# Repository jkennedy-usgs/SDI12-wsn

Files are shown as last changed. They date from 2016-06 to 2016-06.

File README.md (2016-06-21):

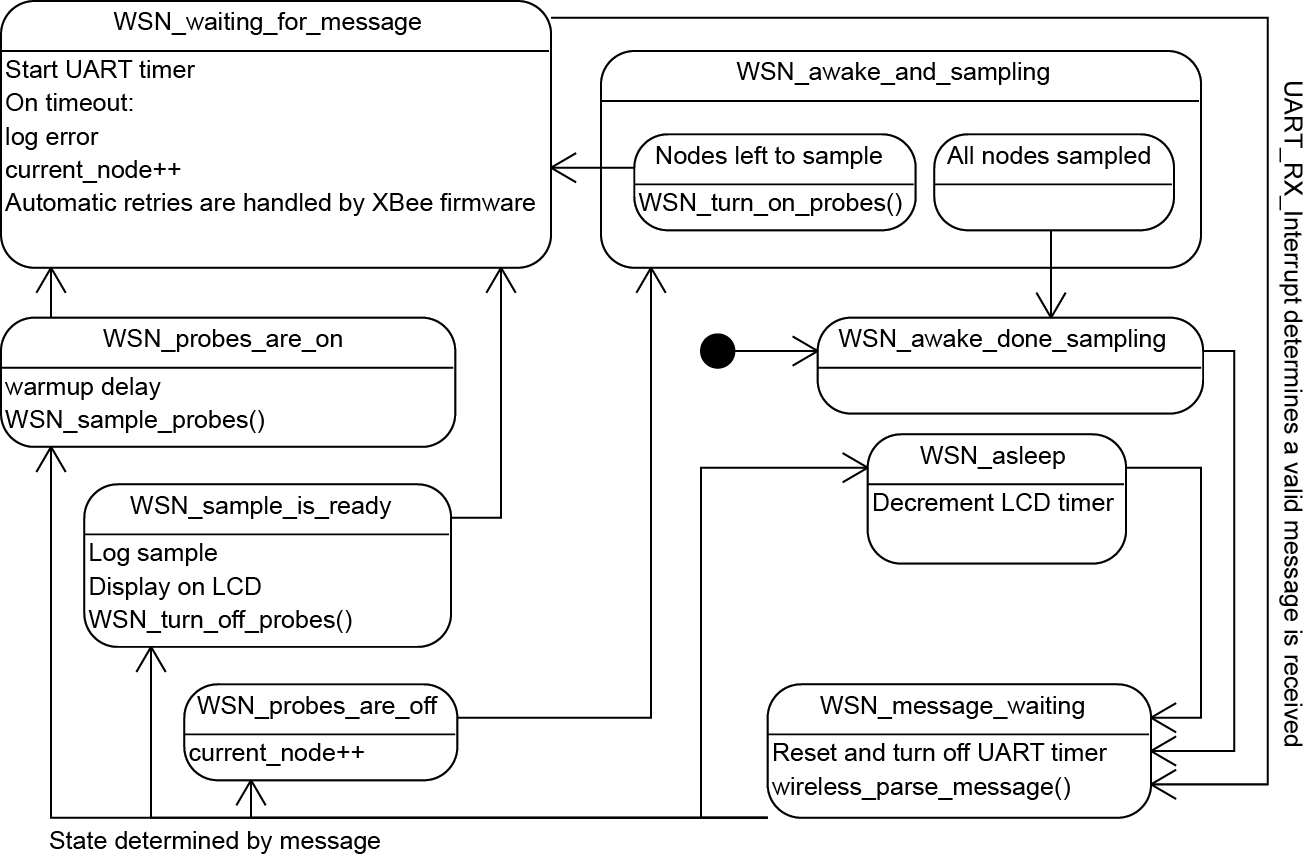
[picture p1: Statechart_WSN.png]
State chart

# SDI12-wsn
C interface for SDI-12 communication on Atmel AVR and XBee nodes

This project is intended to allow wireless sensor networks - in particular, XBee devices - to be deployed at dataloggers with a host SDI-12 port. The data logger issues normal SDI-12 commands to a "bridge" device, which coordinates communication among the devices in the wireless sensor network. The benefit is that a local wireless network, using low-power radios, can relay data through an existing satellite telemetry network that uses data loggers with (usually ubiquitous) SDI-12 ports.

Additional detail is provided in the conference abstract and poster here:
https://www.researchgate.net/publication/266385447_Expanding_the_Usefulness_of_Existing_Data-Collection_Infrastructure_with_Wireless_Sensor_Networks
and in the draft manuscript provided in the Word document. 

The project includes c code to run on an AVR microcontroller and schematics and board layouts for producing PCB's for the bridge and node unit. The nodes are intended for use with voltage-output soil moisture probes but could be modified for other sensors. NOTE: the project is not designed to implement SDI-12 sensors in a wireless sensor network. 

The project was originally developed in 2010, and bench tested successfully. The hardware has not been field tested. 

The software and related documentation on these web pages were developed by the U.S. Geological Survey (USGS) for use by the USGS in fulfilling its mission. The software can be used, copied, modified, and distributed without any fee or cost. Use of appropriate credit is requested. The USGS provides no warranty, expressed or implied, as to the correctness of the furnished software or the suitability for any purpose. The software has been tested, but as with any complex software, there could be undetected errors.

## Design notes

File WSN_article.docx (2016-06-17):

This draft manuscripts provides an overview of the SDI12-wsn project hosted at https://github.com/jkennedy-usgs/SDI12-wsn. THE MANUSCRIPT HAS NOT BEEN REVIEWED BY USGS AND IS NOT AN OFFICIAL PUBLICATION. It is provided for informational purpose only.

Adaptation of the SDI-12 protocol for easy deployment earth science wireless sensor networks

Jeffrey Kennedy, U.S. Geological Survey

James Wagner, Oregon Research Electronics

Keywords: wireless sensor network, soil moisture, data collection,

Abstract

The SDI-12 protocol, used for data loggers to communicate with hard-wired digital sensors, has been adapted to facilitate the deployment of wireless sensor networks by means of a hardware/firmware bridge unit that relays communication between an SDI-12 enabled data logger and a wireless sensor network. The fundamental benefit is that existing data-collection infrastructure can be readily expanded to take advantage of wireless sensor networking. Unlike other available SDI-12 products, which enable point-to-point wireless communications with SDI-12 enabled sensors, the current effort provides for deployment of low-cost mesh topology, sleeping wireless networks that accommodate any analog-output sensor. The concept is extendable to any particular wireless sensor networking protocol, and is demonstrated using the DigiMesh protocol, 50 mW 900 MHz radios, and dielectric permittivity soil moisture sensors. Although the sleeping nature of wireless sensor networks prevents true implementation of the SDI-12 protocol, whereby sampling is initiated by the host data logger, the system offers considerable potential for the expansion of existing data collection infrastructure.

1. Introduction

Wireless sensor networks—specifically, networks implementing “mesh” topology with low-power radios and “sleeping” to conserve power while not communicating—have long offered the potential for significant advances in the field of environmental data collection (for example, Rundel et al., 2009; Porter, 2005). Although notable protocols (ZigBee, those by Campbell Scientific, Inc., or Memsic, Inc., for example) and deployments (for example, Delin et al., 2005; Barrenetxea, 2008; Ritsema, 2009) have been developed, wide-spread adoption is still hindered by significant challenges in setting up the networks. For example, the ZigBee protocol requires establishing each radio in advance as an end node or router, requiring advance knowledge of where each one will be placed in the field. Real-time operating systems with wireless networking capability, such as TinyOS, implemented in commercially-available hardware such as the MEMSIC Mica2 motes, offer great flexibility at the expense of complexity, and require fairly advanced programming to deploy. Other wireless sensor network (WSN) products, such as the MEMSIC eKo motes, are designed for easy deployment, but must be deployed as a integrated system and are not compatible with existing data collection infrastructure.

To overcome difficulties in deploying WSNs, and to take advantage of existing data collection infrastructure, we have developed a hardware/firmware bridge unit that bridges SDI-12 and WSN communciation. SDI-12 is a ubiquitous protocol found on thousands of data loggers worldwide, designed to allow multiple (wired) sensors on a single bus. The system described can be deployed with no greater difficulty than any other SDI-12 sensors. Both hardware and firmware are provided in the public domain, and are designed in such a way as to be easy to build and deploy. Furthermore, the cost of the hardware is low – about $80 USD per remote radio, and cheaper if produced in quantity. The online supplement to this article contains source code, printed circuit board (PCB) layouts, and a bill of materials.

WSNs are ideally suited to soil moisture measurement, and many successful implementations have been demonstrated (for example, Bogena et al., 2010; Ritsema et al., 2009; Cano et al., 2007). A primary reason is the low power requirements of typical soil moisture probes – typically 10’s of mA only during excitation and measurement. Furthermore, soil moisture at depths deeper than within a few cm of the surface varies slowly, meaning nodes can be sleeping much of the time, saving power. Finally, soil moisture demonstrates significant spatial variation, particularly during dry periods (Western et al., 1999) and many distributed measurements are helpful to adequately characterize an area. In the United States, soil moisture is a spatially under-sampled component of the hydrologic cycle (a map showing current soil moisture measurement sites is at http://az.water.usgs.gov/projects/soilmoisture). Rainfall is well-characterized by the National Weather Service’s NEXRAD Doppler radar sites, and streamflow is well-characterized by over 7,000 gaging stations operated by the U.S. Geological Survey. Several satellite missions have made great progress towards remote soil moisture sensing, but still require adequate ground truthing to ensure accuracy (such as the recent CanEx-SM10 experiment). By making it easy to add distributed soil moisture measurements to existing data collection sites, the SDI-12 to WSN bridge presented here can help increase the spatial distribution of soil moisture data, with benefits to agriculture, flood forecasting, drought monitoring, and other fields.

2. The SDI-12 protocol

SDI-12 (Serial Data Interface – 1200 baud, www.sdi-12.org) is a protocol developed by the U.S. Geological Survey and private industry to allow digital communication between a host data logger and sensors. Compared to analog sensors, this allows longer cable distances between data logger and sensor. Other advantages are that multiple sensors, up to 50 or more, can be deployed at a single data logger, and sensors can do calculations, such as converting voltage or current measurements to useable data such air pressure, within the sensor. SDI-12 ports are found on nearly every data logger sold for earth science data acquisition in the past 10 years; the USGS alone maintains over 7000 data loggers at gaging stations, each with an SDI-12 port. This ubiquity, together with the fact that nearly all currently deployed SDI-12 data loggers are part of existing data collection networks, where data is relayed to a central repository via radio, cell-phone, or satellite telemetry, or collected manually on a regular basis, makes the SDI-12 an ideal candidate for the incorporation of WSN.

The basic SDI-12 protocol involves a host data logger initiating measurement at a specific sensor. Each sensor has an address set using a hardware switch, or via SDI-12 commands. Upon receiving a command to start measurement, the sensor replies with the number of seconds until a measurement is complete, and the number of measurements that will be returned. Upon completion of this period, the data logger issues a request for data, to which the sensor replies with one or more measurements. Alternatively, the sensor may respond with a service request before the previously specified elapsed time, upon which the data logger issues a request for data. Other SDI-12 commands expand upon this basic protocol, such as allowing concurrent measurements to be made at multiple sensors, or requiring the sensor to transmit a checksum to verify data integrity. Non-measurement SDI-12 commands are used to set sensor addresses, retrieve information (such as manufacturer or sensor type) from a particular sensor, or query the SDI-12 bus to see which sensor addresses are active.

The SDI-12 protocol mandates inverted, 0-5V logic levels on a single bidirectional bus. In addition, SDI-12 data loggers provide +12V for sensor power (if needed) and ground.

A fundamental limitation of integrating SDI-12 with a sleeping WSN is that while nodes are asleep, they are unresponsive to incoming messages (this could be remedied by using a WSN protocol incorporating “wake on receive” functionality, with a concomitant increase in power consumption). In the current design, the network sleeps for fifteen minutes between soil moisture measurements, making it unrealistic to expect the host data logger to wait until the network is awake before a measurement is returned. Therefore, the WSN is sampled each time it wakes, and data are stored in the bridge unit memory. When an SDI-12 command for a measurement is received, the bridge unit returns the average of stored, previously sampled data. This is not present a serious limitation when sampling a slowly varying property such as soil moisture. For more rapidly varying phenomena, the sleep time can be shortened as appropriate, keeping in mind a more robust power supply may be needed. An additional consideration when deploying at data loggers with existing telemetry is the increased bandwidth needed for the additional WSN data. The present design stores 16 soil moisture samples at 15-minute intervals, to be retrieved by the SDI-12 data logger at 4 hour intervals. Sleep and wake times, and the number of samples to store in memory from which to compute the average, are readily set by modifying the source code but are not intended to be changed during deployment.

3. Wireless Sensor Networks

The basic concept of a WSN is a group of sensors, or nodes, deployed over a geographic area to collect data about a spatially distributed condition. Furthermore, it is typically understood to use some form of relaying of messages, or routing, rather than point-to-point communication between a base station and remote node. WSN hardware is usually designed to be inexpensive, with low-power radios relative to the size of the network, and low-power, implementing some type of “sleeping” algorithm whereby nodes enter a reduced functionality state to save power. More advanced WSNs, termed sensor webs (Delin, 2002), are differentiated by the ability to process data at each node and share information with other nodes, thereby increasing the ability to respond to transient environmental phenomena. Sensor webs have proven successful in hydrology-related deployments (Delin et al., 2005), but no commercial hardware is readily available.

WSN protocols are rapidly evolving. To date, the only protocol with any significant adoption among vendors is the ZigBee protocol (www.zigbee.org), an extension of the IEEE 802.15.4 standard. Although ZigBee is available free of charge to non-commercial users, it is not open source and commercial users are required to join the ZigBee Alliance. ZigBee-based projects have been successfully deployed in the earth sciences (for example, Zhu et al., 2005; Bogena et al., 2007).

One alternative to the ZigBee protocol is Digi, Incorporated’s proprietary DigiMesh protocol, implemented in the work presented here. DigiMesh offers several advantages not available with ZigBee. First, every node unit can serve as either an end node or router, and does not need to be configured as such before the network is deployed. Routers can collect data from attached sensors and sleep in coordination with the end nodes. Second, using the ad-hoc on-demand distance routing method, DigiMesh offers self-configuration and self-healing, in which node units automatically determine the most efficient radio links between them, and, if a node unit becomes unresponsive, the network can determine an alternative route. This offers obvious advantages for maintaining continuity of data collection in a remote environment. Finally, the sleeping protocol in DigiMesh is self-synchronizing and is easy to implement. In time, an open source alternative to DigiMesh will likely become available. At present, however, we feel that the advantages outweigh the disadvantages of using this proprietary protocol. Because we implement DigiMesh without modification or access to the internal communications, this project remains in the public domain.

The DigiMesh protocol is implemented using an API framework. Rather than sending data to the node unit directly, API mode encapsulates messages and commands in a packet with ancillary information such as packet number, destination address, event notifications, etc. This adds functionality—in particular, the ability to retrieve digital and analog I/O data from remote nodes directly without needing a separate microcontroller at each node.

4. Design Implementation

The principal consideration in designing the system is ease of deployment. To achieve this, the system is intentionally of limited flexibility—it samples at a predefined interval and accommodates only a single variation of sensor (single-ended analog output). The result is that no programming or other special skills are required.

4.1 Hardware

The hardware design comprises two parts: the bridge unit that physically connects to the SDI-12 host data logger and the remote node units (Figure XX). Each unit requires one radio. The test design utilizes XBee Pro 900 MHz radios, but the design is readily adaptable to other XBee radios and frequencies. PCB layouts for the bridge and node units—included in the online supplement—are readily manufactured at low cost, particularly in volume, by any circuit board manufacturer. The PCB design has also been uploaded to the BatchPCB service and can be ordered directly (http://batchpcb.com/index.php/Products/XXXXX). Where possible, all components are through-hole for ease of assembly. The size of the bridge unit could be reduced if needed by incorporating more surface-mount components.

4.1.1 Bridge unit

The bridge unit comprises 4 main systems: voltage regulation, ESD protection, and level-shifting/buffering/inverting circuits; an Atmel AVR microcontroller; an XBee radio; and an LCD for communicating status messages to the user. No external inputs—buttons or switches—are used or needed.

Both a 5V and 3.3V voltage regulators are needed: the former provides the proper voltage for SDI-12 communication and the latter powers the AVR, XBee, and LCD. Both regulators use 12V input from the SDI-12 bus. ESD protection is as per the SDI-12 protocol. Level shifting, inverting, and tri-stating on the SDI-12 bus are controlled by two ICs. The CMOS SN74AHCT1G125 serves as a tri-state buffer, controlled by an output from the microcontroller. TTL-compatible, it also shifts the 3.3V Tx line from the AVR to 5V. The SN74LVC2GU04 dual inverter gate inverts the AVR UART to match the SDI-12 inverted logic on both the Rx and Tx lines, and shifts the 5V SDI-12 bus to 3.3V.

The Atmel AVR microcontroller used is the ATMEGA644PA. The primary considerations for selecting this IC were dual UARTS, for communication with both the SDI-12 bus and the XBee radio; sufficient I/O to support the LCD and other necessary ports; availability of DIP packaging for ease of assembly; and a JTAG (in-circuit debugging) interface. Other microcontrollers, from AVR or other manufacturers, would be equally suitable. The hardware design implements both SPI and JTAG programming interfaces. A 16 MHz crystal is used; slower frequencies would likely work as well but have not been tested. A reset button provides hard-reset capability. Because power is provided by the host data logger and is presumably robust, power-saving features of the microcontroller have not been implemented; power consumption is relatively low in comparison to the 80 mA consumed by the bridge unit XBee.

The XBee Pro 900 communicates with the AVR via one of the UARTS. Three LED’s connected to the XBee indicate signal strength (RSSI), sleeping status of the network, and network association (lit to indicate the XBee is communicating with others in the network). The XBee mounts in a 2mm pitch socket. A reset button provides hard-reset capability.

An LCD is connected via 4-pin parallel interface to port A of the AVR. The unit is designed to use a 3.3V LCD with a ST 7036 controller, although other units could be easily implemented. No backlight has been implemented but one could easily be added.

4.1.2 Node unit

The node unit is essentially a carrier board for the XBee radio. ADC and digital I/O is handled by the XBee’s onboard AVR microcontroller, as implemented in the Digimesh firmware. ADC is 10-bit, providing accuracy to about 0.0012 V using a 1.25 V voltage reference. The SDI-12 address for each node is set in binary through a DIP switch connected to four of the XBee’s digital I/O, an acceptable solution for addresses 0 through 9 and A through F; higher addresses would require an alternative. A hardware reset switch and “commissioning” button, for facilitating joining the XBee to an existing network, are also included. Probes are connected to the XBee using two, three-position screw terminals.

Power is provided by 2 AA batteries and a 6-cm square solar panel. In initial testing this has been sufficient to provide power through a three day cloudy period; the node unit will run for approximately 5 days on AA batteries alone at the 15 minute sample interval used. XBee Rx (awake, not transmitting) and Tx power requirements are 80 mA and 210 mA, respectively, at 3.3V; standby power is 60 µA. Power regulation is provided by a Maxim MAX856 IC, which is 80% efficient between about 1 mA and 100 mA at a supply voltage between 1.5V and 3.3 V. Efficiency drops to 60% during the short periods when the XBee is transmitting. The MAX856 is capable of sourcing 3.3V down to an input voltage of 0.8 V. It also supplies a 1.25 V voltage reference to the XBee ADC, accurate within 0.8%.

Utilizing a 2 dBi 6” duck antenna, XBee Pro 900 radios have a line-of-sight communication distance of 2 km, and an indoor-urban distance of 140 m, sufficient for nearly all deployments where spatial variability of soil moisture is the variable of interest. Lower-power, cheaper XBee variants could likely be substituted (with possibly some firmware changes). Alternatively, higher gain antennae, including multi-element Yagi up to 15 dBi, are approved. The antenna used in the node unit attaches directly to the XBee. A short extension is used on the bridge unit so that the antenna may be mounted outside the host data logger enclosure.

The node unit enclosure is epoxied to a 45-degree PVC junction, which in turn mounts at the top of a 2 m, 2.54 cm diameter PVC post (fig. field_deployment). Probe cables are routed through the post to minimize the potential for disturbance, and using PVC minimizes the potential for RF interference. Burial of the post to a depth of 0.5 m is sufficient for stability.

4.1.3 Soil moisture probes

The probes used are Decagon, Inc. 10-HS soil moisture sensors. Any other soil moisture probe, or other sensor, that outputs 0 to 1.25 V will be directly compatible with the node unit hardware, and other analog sensors could be used with minimal modification. In response to a 3 to 12 V excitation, the 10-HS outputs a 0.3 to 1.25 V signal, independent of excitation voltage, which is proportional to apparent dielectric permittivity by a fourth-order polynomial. Because of the large permittivity contrast between water and air, volumetric water content can be derived using the well-known Topp equation (Topp and others, 1980), a third-order polynomial. Because the polynomial for determining permittivity is probe-specific, it is not programmed directly into the bridge unit, and must be applied separately either by the host data logger or as a data-processing step.

4.2 Firmware

Firmware consists of a collection of c-language libraries compiled using avr-gcc, a port of the GNU c compiler for AVR microcontrollers. It should be readily adaptable to other platforms and compilers. Program architecture is based around two state machine frameworks, one each for the WSN and the SDI-12 interface. These have been kept independent, so that the same firmware may be adapted to WSN protocols other than DigiMesh, or the SDI-12 code adapted for non-WSN projects. Commented code is available in the online supplement to this article.

The WSN state machine is implemented in main.c. The initialize and interrupt service request (ISR) routines within main.c contain XBee specific code; otherwise, all XBee routines are in wireless_xbee.c. Generic XBee routines, not specific to this implementation, are in xbee_API.c. WSN initialization under DigiMesh involves broadcasting a “node discovery command” to all node units, upon which each one responds in random order with a unique identifier. Once these IDs have been compiled, the initialize routine steps through each node, reading the SDI-12 address assigned on the DIP switch. From this point on, each node unit is referred to internally by the SDI-12 address. These addresses need not be sequential. Memory is reserved for the maximum possible number of nodes, about 20 in the 64k flash memory of the ATMEGA644PA (after space is used for code). The initialize routine also sets the XBee I/O settings (inputs, outputs, and pullup resistors) and writes them to non-volatile memory.

Following initialization, the firmware enters the WSN state machine (fig. 3). Each time a valid XBee packet is received, the UART Rx ISR sets the state to WSN_message_waiting, from which wireless_parse_message is called and sets the appropriate state, depending on the content of the packet. Information about each node, including the XBee address, data from the attached sensors, and communication errors, is stored in the _node struct, and all of these structs are stored in the nodes array. Array node_ids is a lookup table for SDI-12 addresses, where value at the sequential array index (0 through the number of nodes) is the (non-sequential) SDI-12 address. That is, node_ids[0] is the SDI-12 address of the first node found during the node discovery process (which could be 0-9, A-Z, etc.), node_ids[1] is the SDI-12 address of the second node found, and so on.

Requests for data from the SDI-12 data logger are handled by an independent state machine (fig. 4) and the UART Rx ISR on the second AVR UART (which operates independently of the UART used for WSN communication). Because baud rates (1200 and 9600, for SDI-12 and XBee, respectively) are slow relative to the AVR clock (16 MHz), both UARTs can receive and process incoming data simultaneously. SDI-12 code executes in response to Rx or Tx interrupts; pin change interrupt on the SDI-12 bus, timer interrupt, or when the WSN state machine calls sdi12_dotask. The SDI-12 state machine indicates that a request for data has been received by setting a flag (sdi12_msg_signal) equal to the SDI-12 address requested. When this flag is checked by the WSN state machine, the SDI-12 response is prepared, and a pointer set to the memory location of the response. When sdi12_dotask is called, the SDI-12 state machine replies to the host data logger using a Tx interrupt.

References

Barrenetxea, G., Ingelrest, F., Schaefer, G., Vetterli, M., Couach, O., Parlange, M., 2008. SensorScope: out-of-the-box environmental monitoring, Proceedings 2008 International Conference on Information Processing in Sensor Networks, pp. 332-343.

Bogena, H.R., Huisman, J.A., Oberdörster, C., Vereecken, H., 2007. Evaluation of a low-cost soil water content sensor for wireless network applicatioons. Journal of Hydrology 344, 32–42.

Bogena, H. R., Herbst, M., Huisman, J. A., Rosenbaum, U., Weuthen, A., Vereecken, H., 2010. Potential of Wireless Sensor Networks for Measuring Soil Water Content Variability. Vadose Zone Journal 9(4), 1002-1013.

Cano, A., Lopez-Baeza, E., Anon, J.L., Reig, C., Millan-Scheiding, C., 2007. Wireless Sensor Network for Soil Moisture Applications. In: Proceedings International Conference on Sensor Technologies and Applications, Valencia, Spain, pp. 508 – 513. doi 10.1109/SENSORCOMM.2007.4394971.

Delin, K.A., 200. The Sensor Web: A Macro-Instrument for Coordinated Sensing. Sensors 2, 270-285.

Delin, K.A., Jackson, S.P., Johnson, D.W., Burleigh, S.C., Woodrow, R.W., McAuley, J.M., Dohm, J.M., Ip, F., Ferré, P.A., Rucker, D.F., Baker, V.R., 2005. Environmental Studies with the Sensor Web: Principles and Practice. Sensors 5, 103-117.

Porter, J., Arzberger, P., Braun, H.-W., Bryant, P., Gage, S., Hansen, T., Hanson, P., Lin, C.-C., Lin, F.-P., Kratz. T., Michener, W., Shapiro, S., Williams, T., 2005, Wireless sensor networks for ecology, BioScience 55(7), 561-572.

Ritsema, C. J., Kuipers, H., Kleiboer, L., van den Elsen, E., Oostindie, K., Wesseling, J. G., Wolthuis, J.‐W., Havinga, P., 2009. A new wireless underground network system for continuous monitoring of soil water contents. Water Resources Research 45, W00D36. doi:10.1029/2008WR007071.

Rundel, P.W., Graham, E.A., Allen, M.F., Fisher, J.C., Harmon, T.C., 2009. Environmental sensor networks in ecological research, New Phytologist 182, 589–607. doi: 10.1111/j.1469-8137.2009.02811.x.

Topp G.C., Davis, J.L., Annan, A.P., 1980. Electromagnetic determination of soil water content: measurements in coaxial transmission lines. Water Resources Research 16, 574–582.

Western, A.W., Grayson, R.B., Blöschl, G., Willgoose, G.R., McMahon, T.A., 1999. Observed spatial organization of soil moisture and its relation to terrain indices. Water Resources Research 35(3), 797-810. doi:10.1029/1998WR900065

Zhu, Y.W., Zhong, X.X., Shi, J.F., 2006. The design of wireless sensor network system based on ZigBee technology for greenhouse. Journal of Physics: Conference Series 48, 1195–1199. doi: 10.1088/1742-6596/48/1/223.

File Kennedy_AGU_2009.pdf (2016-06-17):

# N23C-1073 Jeff Kennedy, USGS, Arizona Water Science Center jkennedy@usgs.gov

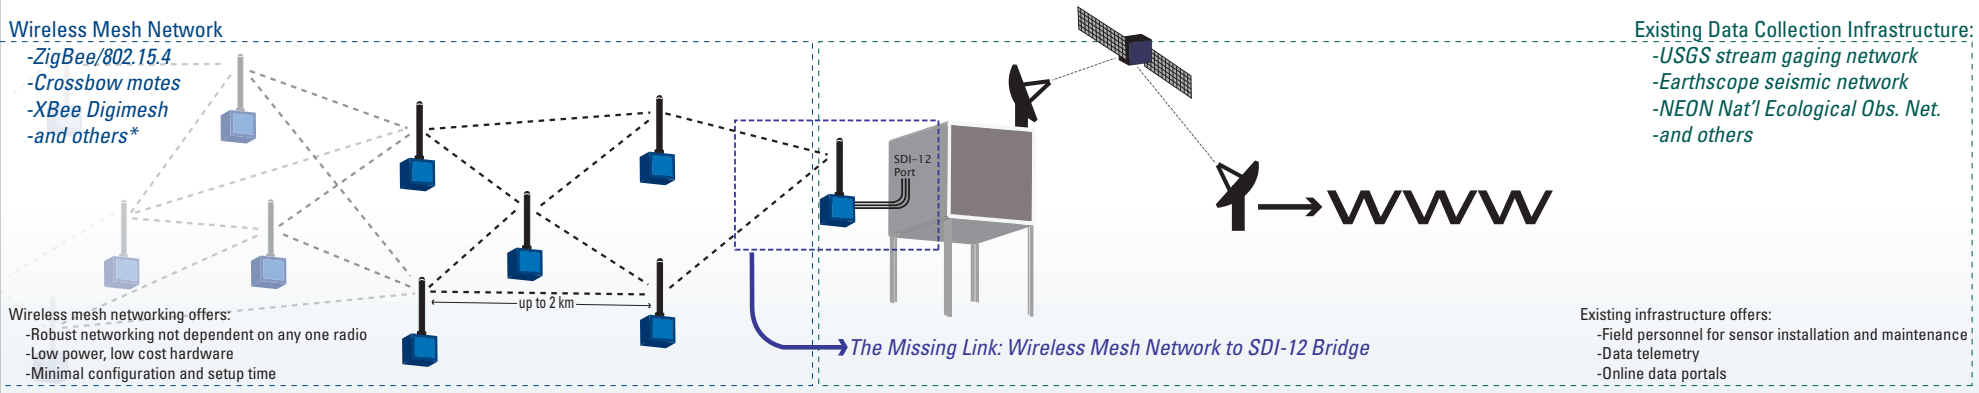
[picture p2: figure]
-USGS stream gaging network -Earthscope seismic network -NEON Nat’l Ecological Obs. Net. -and others; WWW; Wireless Mesh Network -ZigBee/802.15.4 -Crossbow motes -XBee Digimesh -and others*; SDI-12; Port; Existing infrastructure offers:; -Data telemetry -Online data portals; Wireless mesh networking offers:; -Low power, low cost hardware -Minimal configuration and setup time

Wireless Mesh Networking | SDI-12

## Existing Data Collection Infrastructure:

## The Missing Link: Wireless Mesh Network to SDI-12 Bridge

## The Implementation

Currently, off-the-shelf Digi XBee 900 Mhz 50 mW radios* are used. These low-power, spread-spectrum radios provide 2 km line-of-sight range with 6” whip antennas and 8 km range with small Yagi antennas. They can be set to sleep in a very low power mode for up to 4 hours. While sleeping, the radios are unresponsive and consume just 60 μA. At the end of the sleep cycle, each radio wakes simultaneously, ready to measure attached sensors.

At a 15 minute sleep/30 second wake cycle, the radios can sample 2 soil moisture probes using the integrated analog-to-digital converter for an indefinite time if powered by a 6 cm-square solar panel, or up to 2 months if powered solely by 2 AA batteries. Alternatively, the hardware is capable of measuring any sensor with voltage output.

A base station/bridge unit is under development by USGS to coordinate the wireless network, collect data, and format it appropriately for the SDI-12 standard. Custom firmware, written in C, is being written to run on an Atmel AVR microcontroller*. The bridge unit connects directly to an existing datalogger and translates between SDI-12 and the WMN protocol, allowing sensors at each wireless radio to be measured independently.

Once completed, the firmware, hardware schematics, and circuit board designs will be publically available from the author. The target cost of the hardware is $80 for the wireless nodes and $120 for the bridge unit. Also, the project seeks to make available an open-source library of SDI-12 microcontroller software code for other projects.

USGS is currently seeking cooperators for further development and field testing.

Wireless mesh networking (WMN) describes low-power radios arranged so that every radio operates as a repeater, allowing networks to be deployed over a large spatial area with minimal hardware. They can be self-configuring, where the best radio links (”routes”) are discovered automatically; selfhealing, where routes are automatically changed if a radio is lost; and sleeping, offering periods of very low power consumption for minutes or hours at a time.

WMN is reaching a “tipping point” of advanced, low-cost hardware. Widespread adoption by the earth science community, however, is hindered by complex programming requirements.

The project presented here aims to make the advantages of WMN available to a broad audience through the current standard for datalogger-sensor communication, SDI-12.

-Field personnel for sensor installation and maintenance

*Mention of a particular brand name or trademark does not imply endorsement by the U.S. Government.

SDI-12 (Serial Data Interface - 1200 baud) is a protocol designed to allow multiple sensors on a single bus. Therefore, a WMN would be deployable at a station already measuring SDI-12 sensors. The protocol operates by sending command packets, based on ASCII characters, addressed to a specific sensor. The sensor in turn responds with the measured parameter(s).

Nearly every datalogger sold for earth science use in the past 15 years has an SDI-12 port. The USGS alone operates more than 7000 SDI-12 dataloggers. The protocol is well-understood by field technicians.

The SDI-12 protocol allows up to 62 sensors on a single bus, each with multiple parameters. Each wireless radio is considered a sensor, and each sensor at the radio (soil moisture probe, rain gage, etc.) is considered a parameter.

Compared to rainfall and stream gaging networks, the soil moisture component
of the water cycle is poorly sampled:

## http://az.water.usgs.gov/projects/soilmoisture

# The goal: a nationwide soil moisture monitoring network

Wireless mesh networks are well-suited for measurement of soil moisture, which is a spatially variable phenomena that varies slowly over time. Measurements are necessary over a large area, requiring many sensors, but can be made periodically rather than continuously, a characteristic conducive to low-power, sleeping networks.

,
The initial phase of the project aims to deploy 5 wireless soil moisture stations per SDI-12 datalogger, each with two probes, at 15 cm and
30 cm depths. Fifteen-minute samples will be stored in the WMN bridge unit. When a “measure” command is received on the SDI-12 bus from the host datalogger, the WMN bridge unit provides the average of the 15 minute readings collected over the past four hours. Both the 15 minute measurement interval and the four hour averaging period are configurable through SDI-12 commands issued by the datalogger.

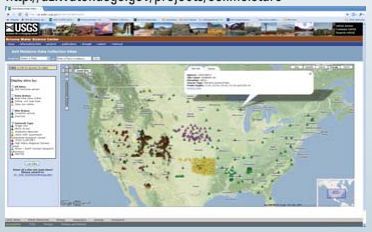
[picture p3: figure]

An enhanced soil moisture monitoring network would benefit runoff and flood forecasting, provide calibration and validation data for climate models, and enable more accurate drought monitoring.

While existing data collection infrastructure offers clear benefits for the deployment of soil moisture sensors, often stations are not ideally located for soil moisture measurement. For example, USGS gaging stations have real-time satellite telemetry providing data immediately to a web-accessible portal. They are typically located, however, on near-stream bank deposits, whereas upland soil moisture measurements would be more representative of the region. Therefore a wireless solution is desirable so that sensors can be located where they are needed.

Although commercial hardware is available to deploy wireless sensors at dataloggers, none combine the characteristics of mesh routing, low-power radios, and low cost that this project seeks to develop. The hardware is specifically designed to be depolyable by field personnel without programming.

Expanding the Usefulness of Existing Data-Collection Infrastructure with Wireless Sensor Networks

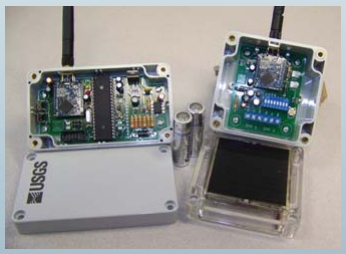
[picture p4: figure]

Hardware under development at USGS. Unit on left is hard-wired to an SDI-12 capable datalogger and coordinates communication with remote wireless nodes, shown on right.

-Robust networking not dependent on any one radio

The concept: Combine the advantages of wireless mesh networking with the universal SDI-12 standard

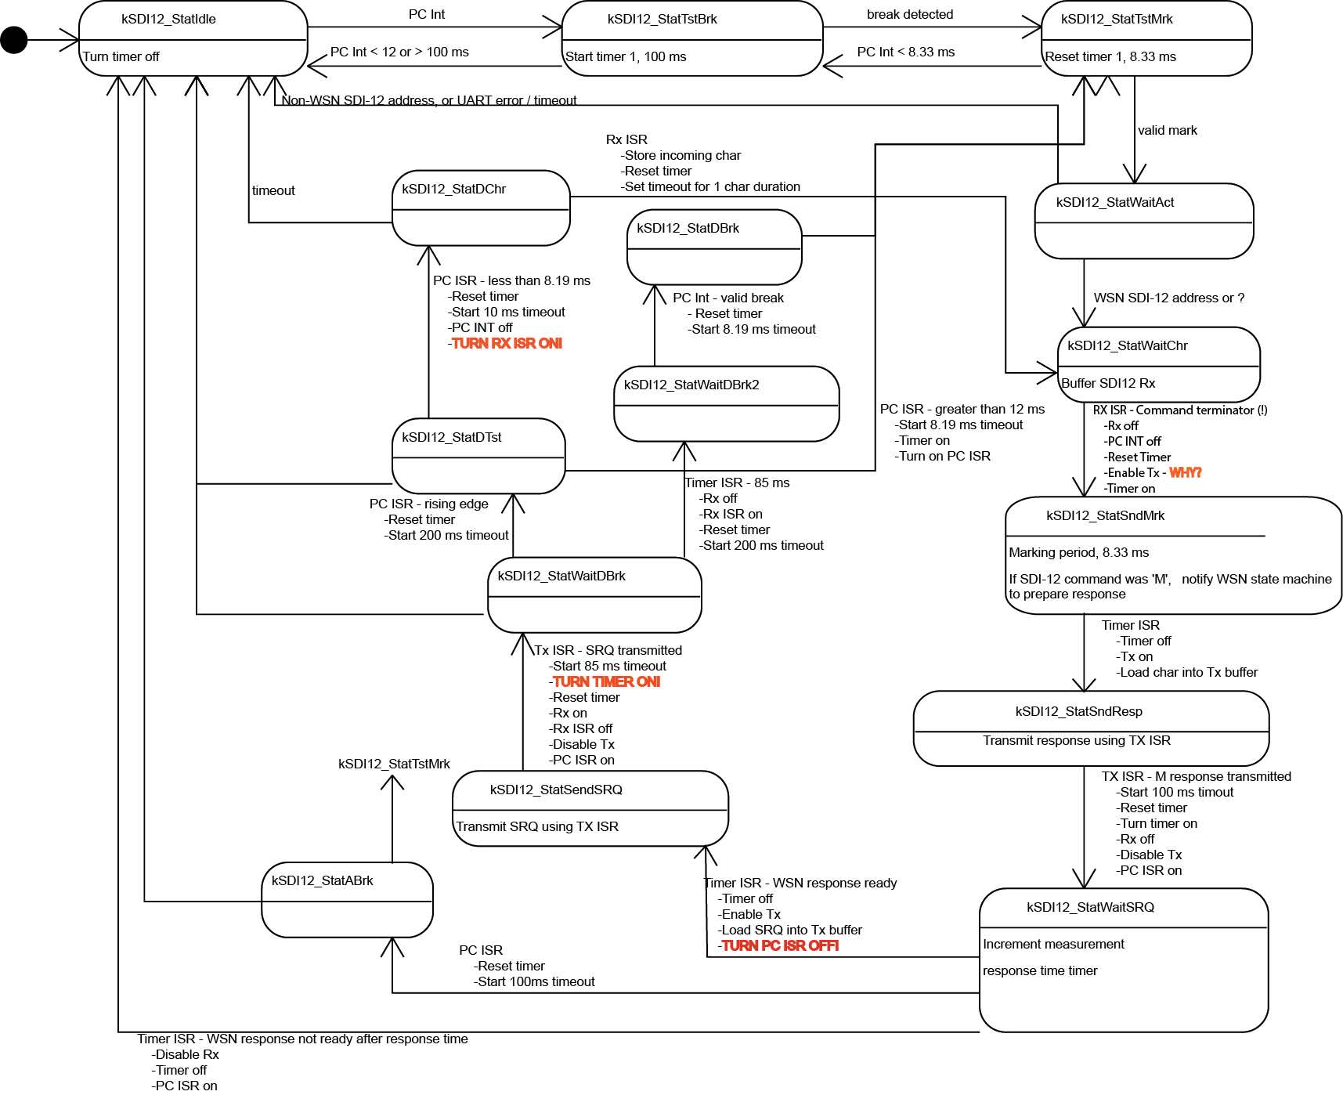
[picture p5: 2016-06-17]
Statechart_SDI12.png

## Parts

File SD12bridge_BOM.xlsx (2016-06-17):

SDI-12 bill of materials
Wireless Node
Qty. | Description | Vendor | Part number
1 | PCB | BatchPCB
1 | Xbee Pro 900 | Xbee, Sparkfun
2 | 2mm, 10 position receptacle | Digikey | S5751-10-ND
2 | Cable gland | Digikey | 377-1630-ND
1 | Momentary microswitch | Digikey | SW961-ND
1 | Enclosure, 3.23x3.15x2.17" | Bud Industries (Mouser, Digikey) | PN-1331-DG
4 | Mounting screws, M3x6mm | Hardware store, Digikey | 29311K-ND
2 | Molex 6373 2 position header | Digikey | WM4200-ND
1 | 900 MHz Duck Antenna, RP-SMA | Sparkfun | WRL-09143
2 | Screw terminal, 3 position, 5 mm | Sparkfun | PRT-08433
1 | DIP switch - 8 position | Sparkfun | COM-08034
1 | Maxim MAX856CSA voltage regulator | Maxim, Mouser | MAX856CSA
1 | 2 position header | Digikey | 609-3469-ND
2 | 68 uF, 10V aluminum electolytic capacitor | Digikey | P908-ND
1 | Inductor, 47uH | Digikey | 811-2044-ND
1 | 1N4004 diode | Digikey | 1N4004GOS-ND
1 | 1N5817 Schottky diode | Digikey | 1N5817GOS-ND
1 | 3mm Green LED | Digikey | 511-1191-ND
1 | 3mm Red LED | Digikey | 511-1191-ND
2 | 75 ohm resistor, 1/6 W | Digikey | 75ETR-ND
1 | 8.2 pF, 50V ceramic capacitor | Digikey | 490-3764-ND
3 | 1 uF, 50V aluminum electrolytic capactior | Digikey | P5174-ND
1 | 0.1 uF, 50V aluminum electrolytic capacitor | Digikey | P820-ND
1 | Solar Cell, 6cm x 6xm | All Electronics | SPL-61
1 | Battery holder, 2xAA | Digikey | BH2AA-PC-ND
2 | Molex connector housing, 2 position, w/ramp/ribs | Digikey | WM2000-ND
4 | Molex terminal, female | Digikey | WM1114-ND
Bridge
Qty. | Description | Vendor | Part number
1 | PCB | BatchPCB
1 | ATMEGA644P | Digikey | ATMEGA644P-20PU-ND
1 | 40-pin IC socket | Digikey | 3M5471-ND
1 | Xbee Pro 900 | Xbee, Sparkfun
2 | 2mm, 10 position receptacle | Digikey | S5751-10-ND
1 | Molex connector housing, 3 position, w/ramp/ribs | Digikey | WM2001-ND | SDI-12 connector
3 | Molex terminal, female | Digikey | WM1114-ND | SDI-12 connector
2 | Molex 6373 2 position header | Digikey | WM4201-ND | SDI-12 connector
1 | TVS Diode | Digikey | 1.5KE20ALFCT-ND | Lightning suppression
1 | 68 uF, 10V aluminum electolytic capacitor | Digikey | P908-ND | power supply
1 | 3.3V LCD - SN74AHCT | Mouser | 790-EADOGM162WA | LCD display
1 | Dual Inverter IC - SN74LVC | Digikey | 296-13276-1-ND | SDI-12 bus
1 | Tri-state buffer | Digikey | 296-4708-1-ND | SDI-12 bus
1 | 5V voltage regulator | Mouser | 512-KA78L05AZTA | power supply for SDI-12 communication
1 | 3.3V voltage regulator | Digikey | 497-1491-5-ND
1 | 3x2 0.1" header | Digikey | 609-3352-ND | SPI programmer port
1 | 5x2 shrouded header | Digikey | MHC10E-ND | JTAG programming part
2 | 22 pF, 50 V ceramic capacitor | Digikey | 490-3708-ND | AVR decoupling caps
1 | 8.2 pF, 50V ceramic capacitor | Digikey | 490-3764-ND | Xbee decoupling cap
1 | .40A resettable fuse | Digikey | F2005-ND | power supply
1 | 10 uF, 50V aluminum electrolytic capacitor | Digikey | P5178-ND
1 | 7.5V Zener diode | Digikey | 1N4737AFSCT-ND | power supply
1 | 16 MHz crystal
 | 100 uF, 50V aluminum electrolytic capacitor |  | P5182-ND

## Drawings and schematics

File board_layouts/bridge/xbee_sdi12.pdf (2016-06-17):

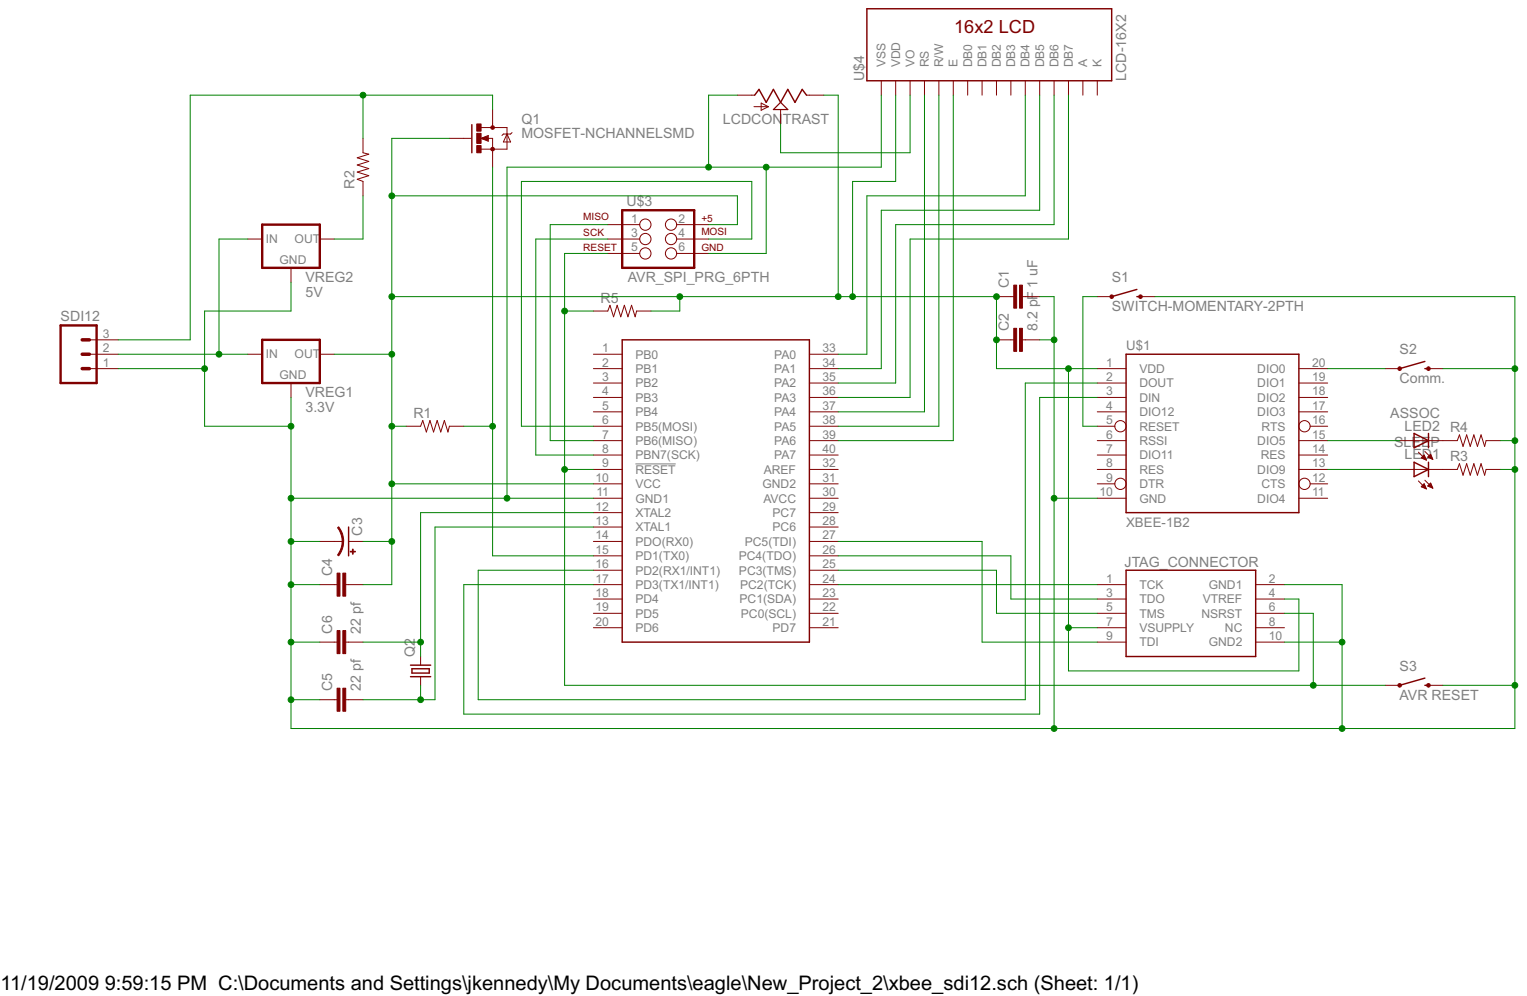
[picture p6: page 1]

11/19/2009 9:59:15 PM C:\Documents and Settings\jkennedy\My Documents\eagle\New_Project_2\xbee_sdi12.sch (Sheet: 1/1)

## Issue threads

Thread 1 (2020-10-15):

Bridge Schematic

egionet, 2020-10-15:
Hi, I am reviewing your schematic to understand the SDI-12 circuitry implemented and noticed RX0 is floating.  Please, could you clarify how the MCU receives data from the SDI-12 sensor?

jkennedy-usgs, 2020-10-15:
In this project the bridge is acting as an SDI-12 sensor, the SDI-12 port in the schematic represents the connection to the host data logger.

SDI-12 uses a single bi-directional line for communication (https://en.wikipedia.org/wiki/SDI-12) i.e. the TX pin handles TX and RX.

egionet, 2020-10-15:
thanks for clarifying, Jeff, and was looking for confirmation.  I worked
for Campbell Scientific - Eric Campbell - the originator of SDI-12 protocol.

On Thu, Oct 15, 2020 at 1:28 AM Jeff Kennedy <notifications@github.com>
wrote:

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

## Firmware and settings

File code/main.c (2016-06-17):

//*****************************************************************************
//	Main program routine for SDI-12 bridge project
//		Jeff Kennedy, USGS
//		January 8, 2011
//
//	This module initializes the wireless sensor network, and runs the WSN state
//	 machine.
//*****************************************************************************

/************************************
TODO:
 1) Xbee sleep should start when first SDI-12 command is received (?)
 2) Implement watchdog timer
*************************************/

/******************************************************************************
 Initialization process:
 1) "Node Discovery" (ND) command is sent to XBee network. Each node responds at a random
 	time with a	packet containing it's address. This address is stored in temp_nodes[]. The
	array index is sequential: first is zero, second is one, etc.
 2) For each node in temp_nodes, do these steps in order:
 	-Initialize IO on the Xbee with appropriate inputs and pullups.
	-Sample Xbee IO. This returns the SDI-12 address from the SIP switch. The SDI-12 address
	is used as the array index of nodes[].
	-Set Xbee sleep mode with specified sleep and wake times.
 3) Start Xbee sleep mode.
 4) call SDI-12 initialization function.
******************************************************************************/

/******************************************************************************
 Typical program flow after initialization:
 1) Receive "wireless network is awake" message
 2) Display LCD message while network syncnronizes
 3)	Sample each node:
 	-turn on sensors (aka probes)
 	-warmup delay
 	-sample probes
 	-qaqc sample
 	-log sample
 	-turn off probes
 4) Display "Done sampling" on LCD
 5) Do nothing while waiting for "wireless network is asleep" message

All the while, network is responsive to incoming SDI-12 data requests.
******************************************************************************/

#include <util/delay.h>
#include <stdlib.h>
#include <ctype.h>
#include <avr/io.h>
#include <avr/interrupt.h>
#include <stdio.h>
#include <stdbool.h>
#include <avr/wdt.h>
#include "RingBuff.h"
#include "dogm.h"
#include "sdi12.h"
#include "nodes.h"
#include "main.h"
#include "uart.h"
#include "wireless_xbee.h"

// extern vars that keep track of node information.
uint8_t number_of_nodes;
uint8_t number_of_nd_nodes;
_temp_node 	temp_nodes[NODE_ARRAY_SIZE];
_node nodes[NODE_ARRAY_SIZE];
uint8_t node_ids[NODE_ARRAY_SIZE];
_ADC_sample ADC_sample;

// Keeps track of which node is being sampled, varies from 0 to number_of_nodes-1. It's NOT the SDI-12 address.
// The SDI-12 address is node_ids[current_node].
uint8_t current_node;

// Vars for Rx ISR
volatile bool next_byte_is_len1;
volatile bool next_byte_is_len2;
volatile uint16_t xbee_incoming_length;
volatile uint8_t current_byte;
volatile uint32_t checksum;

// Vars for timer
volatile uint16_t overflows;
uint16_t overflow_counter;
uint16_t seconds;
volatile bool timer_done;

// Vars for state machine
bool initialized;
volatile uint8_t init_status = IO_UNINITIALIZED;
bool newly_asleep = true;
volatile uint8_t state = kWSN_StatNodeDiscovery;

// functions
void start_timer(uint16_t counts);
void reset_timer();
void initialize();

int main()
{
	sdi12_msg_signal = 0xff;
	char lcd_string[10];
	DDRB = (1<<DDB0);
	initialize();

	while (1)  {

	//SDI-12 routines execute when sdi12_dotask() is called, OR on these interrupts:
	//	-TX
	//	-RX
	//	-Timer 1
	//	-Pin change on SDI-12 bus.
		sdi12_dotask();
		if ( sdi12_msg_signal != 0xff ) {
			//dogm_clear();

			sdi12_DataPtr = node_prep_SDI12_msg(sdi12_msg_signal);
			sdi12_msg_signal = 0xff;
			//dogm_puts(sdi12_DataPtr);
		}

	// Main WSN state machine
		switch ( state )  {

			//During normal program flow, this state exits when RX ISR sets state to kWSN_StatMessageWaiting
			case kWSN_StatWaitingForMessage:
				if ( timer_done )  {
					dogm_clear();
					dogm_puts( "No response!" );

					// Log error
					nodes[node_ids[current_node]].UART_timeouts++;
					start_timer(DISPLAY_DELAY_SHORT);
					state = kWSN_StatNextNode;
				}
			break;

			case kWSN_StatPacketError:
				// Log error
				nodes[node_ids[current_node]].Packet_errors++;
				dogm_puts( "Packet error!" );
				start_timer(DISPLAY_DELAY_SHORT);
				state = kWSN_StatNextNode;
			break;

			case kWSN_StatMessageWaiting:
				//Turn off timer, because a message was received. Timer isn't
				// used during initialization routine.
				if ( initialized ) {
					reset_timer();
				}
				state = wireless_parse_message( initialized );
			break;

			case kWSN_StatBeforeSampling:
				dogm_clear();
				dogm_puts("Network awake");
				start_timer( NETWORK_AWAKE_DELAY );
				state = kWSN_StatWarmup;
			break;

			case kWSN_StatWarmup:
				if ( timer_done )  {
					state = kWSN_StatSampling;
				}
			break;

			case kWSN_StatSampling:
				if ( current_node < number_of_nodes )  {	// 0-index, haven't sampled all the probes yet
					dogm_clear();
					itoa(node_ids[current_node], lcd_string, 10);
					dogm_puts(lcd_string);

					start_timer( UART_TIMEOUT );
					state = kWSN_StatWaitingForMessage;

					wireless_turn_on_probes(node_ids[current_node]);
				}
				else  {		// All probes have been sampled
					dogm_clear();
					dogm_puts("Done sampling");

					newly_asleep = true;
					state = kWSN_StatDoneSampling;
				}
			break;

			// Probes are on, so start warmup timer
			case kWSN_StatProbesOn:
				start_timer( SAMPLE_DELAY );
				state = kWSN_StatProbeWarmup;
			break;

			case kWSN_StatProbeWarmup:
				if ( timer_done )  {	//Warmup timer has expired
					start_timer( UART_TIMEOUT );
					state = kWSN_StatWaitingForMessage;
					wireless_sample_DIO( nodes[node_ids[current_node]].SL, nodes[node_ids[current_node]].SH );
				}
			break;

			case kWSN_StatSampleReady:
				if ( node_validate_sample(ADC_sample.ADC1) )  {
					nodes[ADC_sample.node].probe[0].data[nodes[ADC_sample.node].current_sample] = ADC_sample.ADC1;
					node_incr_data_count( ADC_sample.node, 0 );
				}
				else  {
					nodes[ADC_sample.node].probe[0].data[nodes[ADC_sample.node].current_sample] = 0;
					node_decr_data_count( ADC_sample.node, 0 );
				}

				if ( node_validate_sample(ADC_sample.ADC2) )  {
					nodes[ADC_sample.node].probe[1].data[nodes[ADC_sample.node].current_sample] = ADC_sample.ADC2;
					node_incr_data_count( ADC_sample.node, 1 );
				}
				else  {
					nodes[ADC_sample.node].probe[1].data[nodes[ADC_sample.node].current_sample] = 0;
					node_decr_data_count( ADC_sample.node, 1 );
				}

				dogm_gotoxy(2,0);
				//Plus one to convert from 0-indexed array to 1 through 16
				itoa(nodes[node_ids[current_node]].current_sample + 1, lcd_string, 10);
				dogm_puts(lcd_string);
				dogm_puts("of16 Avg");

				if( nodes[node_ids[current_node]].current_sample + 1 < 10 )
					dogm_puts(" ");

				// Display average values
				itoa(node_calculate_average(ADC_sample.node,0), lcd_string, 10);
				dogm_puts(lcd_string);
				itoa(node_calculate_average(ADC_sample.node,1), lcd_string, 10);
				dogm_gotoxy(12,1);
				dogm_puts(lcd_string);

				// Display sampled values
				dogm_gotoxy(0,1);
				itoa(ADC_sample.ADC1, lcd_string, 10);
				dogm_puts(lcd_string);
				dogm_puts(",");
				itoa(ADC_sample.ADC2, lcd_string, 10);
				dogm_puts(lcd_string);

				// Increment current_sample for the current_node
				node_incr_sample_idx(ADC_sample.node);

				start_timer( UART_TIMEOUT );
				state = kWSN_StatWaitingForMessage;
				wireless_turn_off_probes( node_ids[current_node] );
			break;

			case kWSN_StatProbesOff:
				start_timer( DISPLAY_DELAY );
				state = kWSN_StatNextNode;
			break;

			case kWSN_StatNextNode:
				if ( timer_done )  {
					current_node++;
					state = kWSN_StatSampling;
				}
			break;

			// Nothing to do
			case kWSN_StatDoneSampling:
			break;

			case kWSN_StatAsleep:
				if ( newly_asleep )  {
					seconds = SLEEP_SECONDS;
					start_timer( OVERFLOWS_PER_SECOND );
					dogm_clear();
					dogm_puts("Network asleep");
					dogm_gotoxy(0,1);
					dogm_puts("Awake in:");
					dogm_gotoxy(14,1);
					dogm_putc('s');
					current_node = 0;
					newly_asleep = false;
				}
				else if ( timer_done )  {
					start_timer( OVERFLOWS_PER_SECOND );
					seconds = seconds - 1;
					dogm_gotoxy(10,1);
					if ( seconds < 1000 && seconds >= 100 )
						dogm_putc('0');
					else if ( seconds < 100 && seconds >= 10 )
						dogm_puts("00");
					else if ( seconds < 10 )
						dogm_puts("000");
					itoa(seconds, lcd_string, 10);
					dogm_puts(lcd_string);
				}
			break;

			case kWSN_StatNodeDiscovery:
				if ( timer_done )  {
					if ( number_of_nd_nodes == 0 ) {
						dogm_clear();
						dogm_puts("No nodes found!");
						dogm_gotoxy(0,1);
						dogm_puts("restarting...");
						//wdt_enable(WDTO_120MS);
					}
					else  {
						dogm_clear();
						dogm_puts("ND Done!");
						_delay_ms(1000);
						dogm_clear();
						dogm_puts("Reading SDI-12");
						dogm_gotoxy(0,1);
						dogm_puts("Adresses:");
						overflows = 0;
						state = UNINITIALIZED;
						// start timer for assigning SDI-12 addresses - if it timeouts, restart
					}
				}
			break;

			// This is Xbee-specific
			case UNINITIALIZED:
				if ( number_of_nodes <  number_of_nd_nodes )  {
					switch ( init_status )  {

						//Message has been sent; expecting a response
						case INIT_WAITING:
						break;

						case IO_UNINITIALIZED:
							init_status = INIT_WAITING;
							wireless_initialize_IO(temp_nodes[number_of_nodes].SL,temp_nodes[number_of_nodes].SH);
						break;
						case ADDR_UNINITIALIZED:
							init_status = INIT_WAITING;
							wireless_sample_DIO(temp_nodes[number_of_nodes].SL,temp_nodes[number_of_nodes].SH);
						break;
						case ADDR_INITIALIZED:
							init_status = INIT_WAITING;
							wireless_start_network_sleep(temp_nodes[number_of_nodes].SL,temp_nodes[number_of_nodes].SH);
					}
				}
				else {
					dogm_clear();
					dogm_puts("Starting sleep");
					_delay_ms(500);
					initialized = true;
					wireless_start_sleep();
					sdi12_init();
					state = kWSN_StatDoneSampling;
				}
			break;
		}
	}
}

// This is XBee-specific
ISR(USART1_RX_vect)
{
	uint8_t ReceivedByte = UDR1;
	current_byte++;

	if ( next_byte_is_len2 )  {
		xbee_incoming_length = ReceivedByte;
		next_byte_is_len2 = false;
		checksum = 0;
	}
	else if ( next_byte_is_len1 )  {
		next_byte_is_len1 = false;
		next_byte_is_len2 = true;
	}
	else if ( ReceivedByte == API_start_delimiter )  {
		next_byte_is_len1 = true;
		xbee_incoming_length = 0;
		current_byte = 1;
		BUFF_InitialiseBuffer();
	}
	else
		checksum += ReceivedByte;

	BUFF_StoreBuffByte(ReceivedByte);

	if ( current_byte == xbee_incoming_length + 4 )  {
		if( (uint8_t) checksum == 0xFF )  {
  			state = kWSN_StatMessageWaiting;
		}
	}
}

void initialize()
{
	// read reset flags
	if ( MCUSR ) {
		uint8_t temp = MCUSR;
	}

	// clear reset flags
	MCUSR  &= ~((1<<JTRF)|(1<<WDRF)|(1<<BORF)|(1<<EXTRF)|(1<<PORF));
	wdt_disable();
	//WDTCSR |= (1<<WDCE);
	//WDTCSR &= ~(1<<WDE);
	/* Turn off WDT */
	//WDTCSR = 0x00;

	// setup timer prescaler (divide by 1024)
	TCCR0B = (1<<CS02) | (1<<CS00);

	// initialize ring buffer for UART1 Rx interrupt
	BUFF_InitialiseBuffer();

	uart_init();

	dogm_init();
	dogm_clear();
	dogm_puts("Starting up...");
	_delay_ms(2000);
	dogm_clear();
	dogm_puts("Node Discovery");
	dogm_gotoxy(0, 1);
	dogm_puts("Found:");

	// set timer0 for node discovery
	sei();
	start_timer(ND_PERIOD);

	// issue node_discover command - response is handled by RX1 interrupt
	wireless_node_discover();
}

void start_timer(uint16_t counts)
{
	overflow_counter = counts;
	overflows = 0;
	timer_done = false;
	TIMSK0 |= (1<<TOIE0);
}

void reset_timer()
{
	timer_done = false;
	overflows = 0;
	TIMSK0 &= ~(1<<TOIE0);
}

ISR(TIMER0_OVF_vect)
{
	overflows++;

	if (overflows >= overflow_counter) {
		timer_done = true;
		overflows = 0;
		TIMSK0 &= ~(1<<TOIE0);
	}
}

void wd_start(void)
{
wdt_reset();
MCUSR &= ~(1<<WDRF);
WDTCSR |= (1<<WDCE) | (1<<WDE); //needed by manual p 50
WDTCSR = 68; // = WDIE=1, WDP2=1, WDE=0 (no reset)
return;
}

ISR(BADISR_vect)
{
}

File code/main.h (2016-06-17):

#ifndef MAIN_H
#define MAIN_H

#include <inttypes.h>
#include <stdbool.h>

#include <stdlib.h>
#include <stdio.h>
#include <stdbool.h>


#define kWSN_StatMessageWaiting			1
#define kWSN_StatWaitingForMessage		2
#define kWSN_StatAsleep					3
#define kWSN_StatBeforeSampling			4
#define kWSN_StatWarmup					5
#define kWSN_StatSampling				6
#define kWSN_StatDoneSampling			7
#define kWSN_StatProbesOn				8
#define kWSN_StatProbeWarmup			9
#define kWSN_StatProbesOff				10
#define kWSN_StatSampleReady			12
#define kWSN_StatNextNode				13
#define kWSN_StatPacketError			14
#define kWSN_StatNodeDiscovery			15
#define UNINITIALIZED 					0



#define SAMPLE_DELAY					20						// delay between turning probes on and reading ADC
#define NETWORK_AWAKE_DELAY				100						// delay between "network woke up message" and starting to sample probes
#define DISPLAY_DELAY					200
#define DISPLAY_DELAY_SHORT				40
#define ND_PERIOD						1000

#define OVERFLOWS_PER_SECOND 			61
#define UART_TIMEOUT					200

#define NO_SLEEP_MESSAGES				false
#define SEND_SLEEP_MESSAGES				true

// Sleep times for initial setup.
#define SETUP_SLEEP_TIME 				0x0010
#define SETUP_WAKE_TIME 				0x1530
// Sleep times used during operation, after initial setup:
#define SLEEP_TIME 						1000					// 10's msec; 	0xFFFF~11min.,  03E8 = 10 sec, 1770 = 60 sec., 7530 = 300 sec.
#define WAKE_TIME 						25000					// msec; 		0x1388 = 5 sec, EA60 = 60 sec, 7530 = 30 sec.
#define SLEEP_SECONDS 					(SLEEP_TIME/100)		// for lcd display

// typedefs




typedef struct
{
	uint16_t	ADC1;
	uint16_t	ADC2;
	uint8_t		node;
} _ADC_sample;

// GLOBAL VARIABLES


extern volatile 	uint8_t init_status;
extern _ADC_sample	ADC_sample;


#endif
